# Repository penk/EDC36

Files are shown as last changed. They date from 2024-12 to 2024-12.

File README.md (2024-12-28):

## EDC36 - Minimalist 36-Key Split Keyboard (Reversible PCB)

The EDC36 is a split keyboard designed with simplicity and portability in mind. 

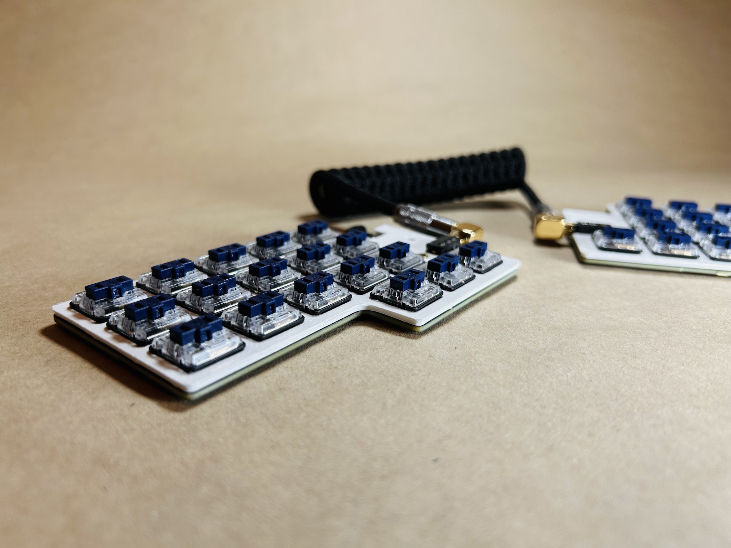
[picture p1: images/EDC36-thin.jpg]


## Bill of Materials (BOM)

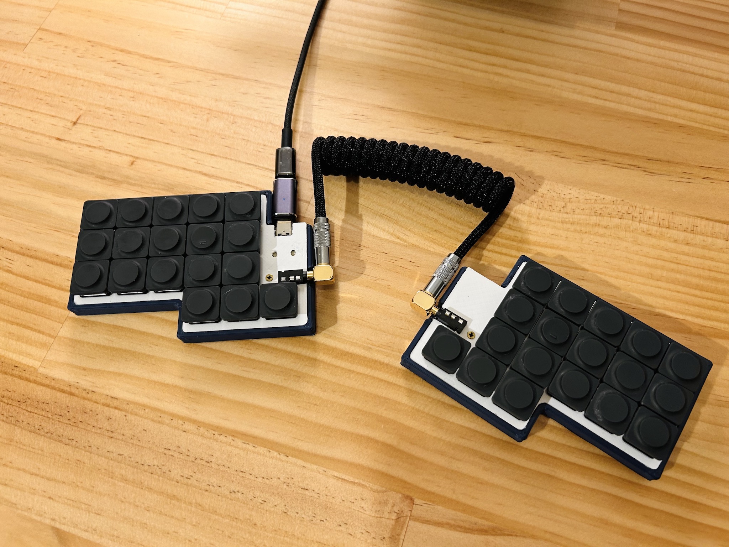
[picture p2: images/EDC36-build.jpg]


Quantity | Item
--- | ---
1 | RP2040-Zero (left half)
1 | RP2040-Tiny (right half)
2 | EDC36 PCB
36 | Choc v1 (PG1350) switches and keycaps 
36 | 1N4148SOD-123 diodes
2 | Audio jack 4-poles (TRRS)
2 | EDC36 case & plate
10 | M2×3 heat-set threaded inserts
10 | M2×5 countersunk screws

## Production Files

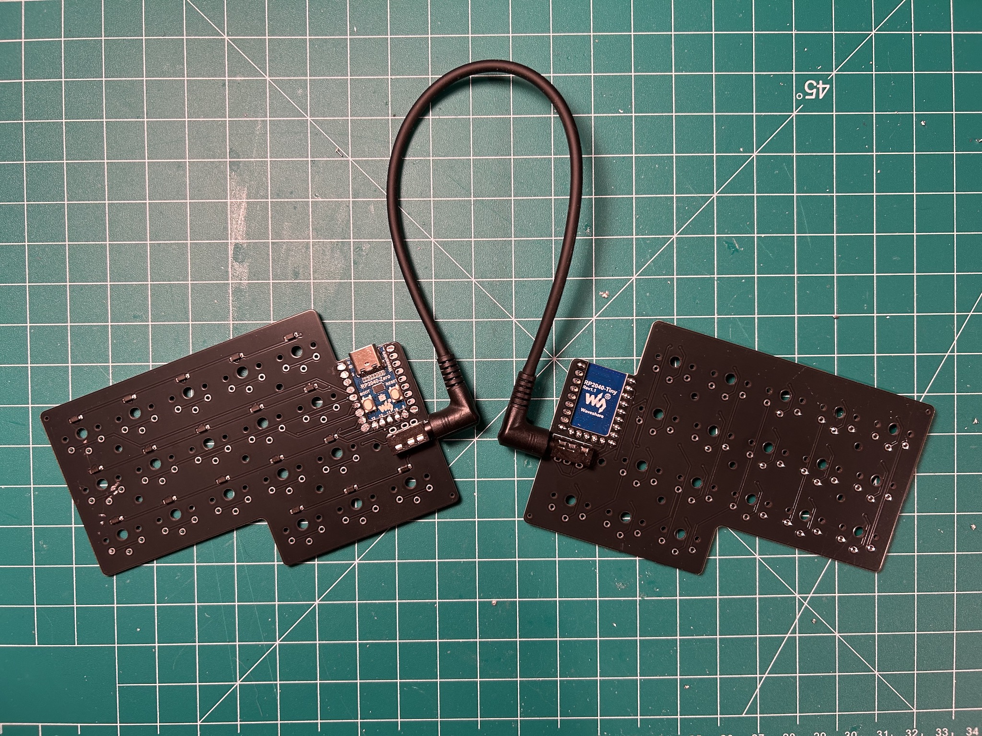
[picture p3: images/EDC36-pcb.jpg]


To place an order for the EDC36 PCB:

- Use the Gerber files available in the [production/](production/) folder.
- Optionally, the [BOM](production/BOM.csv) and [CPL](production/CPL.csv) files can be utilized with a PCBA service. All diodes are soldered to the front (top) side of the board.

The complete PCB design project is available in the [kicad/](kicad/) folder.

## 3D Printable Files

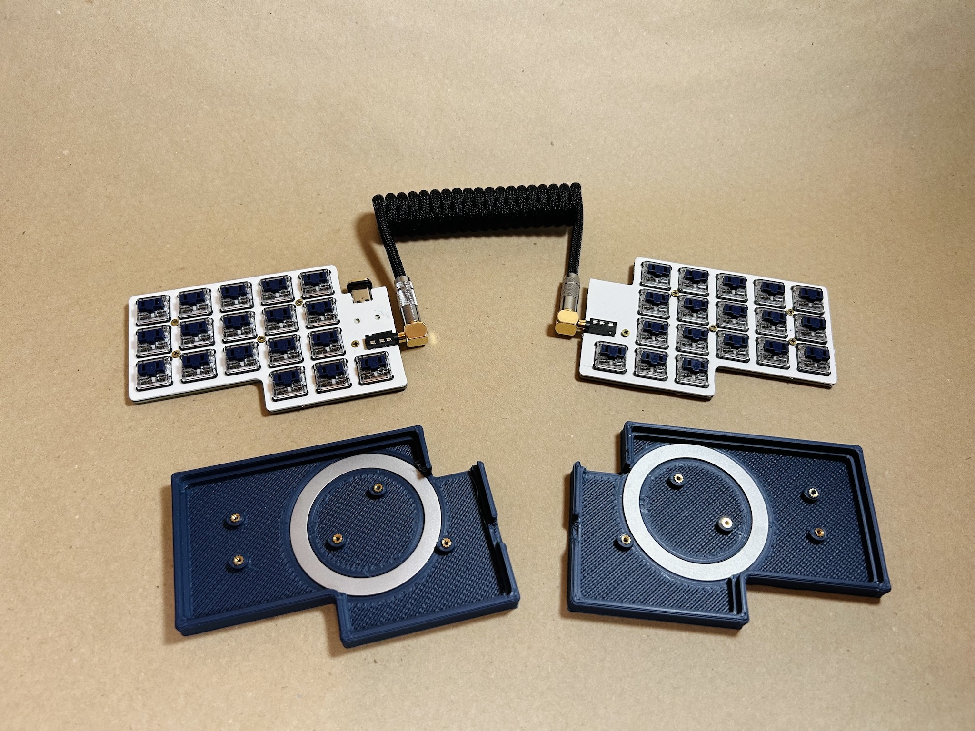
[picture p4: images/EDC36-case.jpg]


Print the case and plate using the provided [STL files](case/).

## Firmware

Precompiled VIA-enabled firmware:

- Flash `penk_edc36_default.uf2` under [firmware/](firmware/) to the RP2040 MCUs.
- Load the [via.json](firmware/QMK/keyboards/edc36/via.json) file in `Design` tab for [VIA](https://usevia.app) configuration.

QMK source is available under [firmware/QMK/keyboards/edc36](firmware/QMK/keyboards/edc36).

## Copyright and License
Copyright (c) 2024 Penk Chen. All rights reserved.

All files are licensed under the MIT license. For more information, see the [LICENSE](LICENSE).

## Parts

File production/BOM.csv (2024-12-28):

Designator | Footprint | Quantity | Value | LCSC Part #
D1, D10, D11, D12, D13, D14, D15, D16, D17, D18, D2, D3, D4, D5, D6, D7, D8, D9 | Diode_SOD-123 | 18 | Diode | C2972760

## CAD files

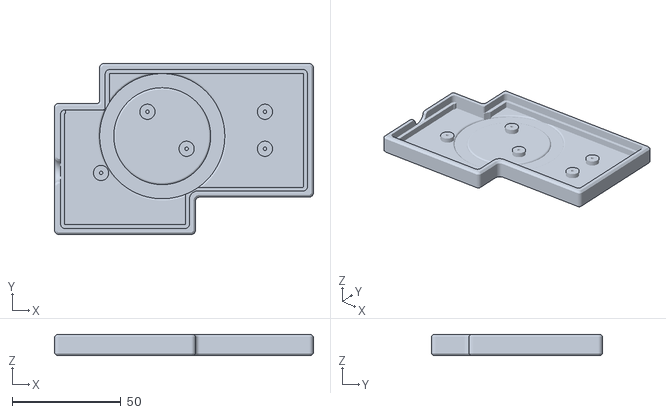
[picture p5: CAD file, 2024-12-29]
case/EDC36-case-right.stl
119.0 x 78.6 x 9.80

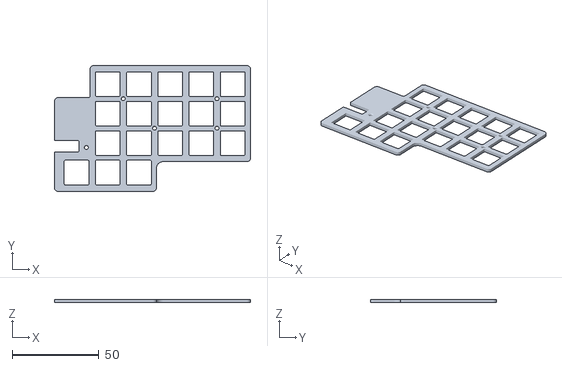
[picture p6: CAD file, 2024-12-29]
case/EDC36-plate-right.stl
113.0 x 72.6 x 2.00

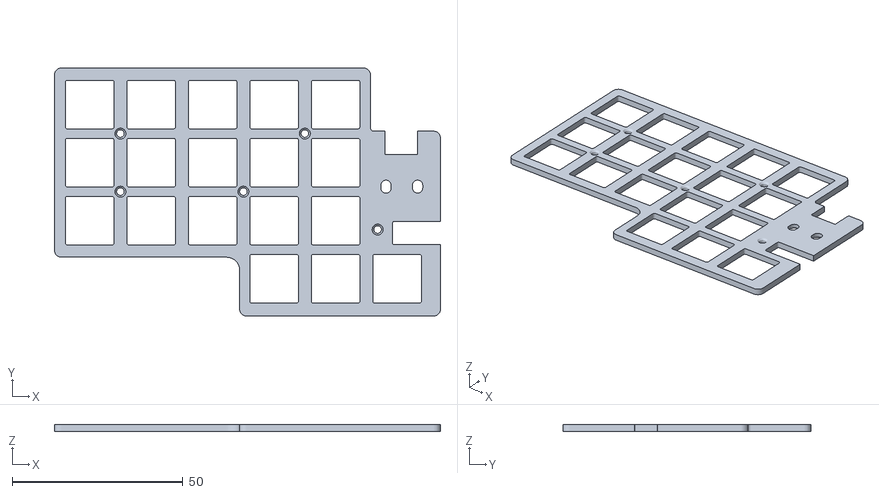
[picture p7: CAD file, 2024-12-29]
case/EDC36-plate-left.stl
113.0 x 72.6 x 2.00

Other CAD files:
case/EDC36-case-left.stl

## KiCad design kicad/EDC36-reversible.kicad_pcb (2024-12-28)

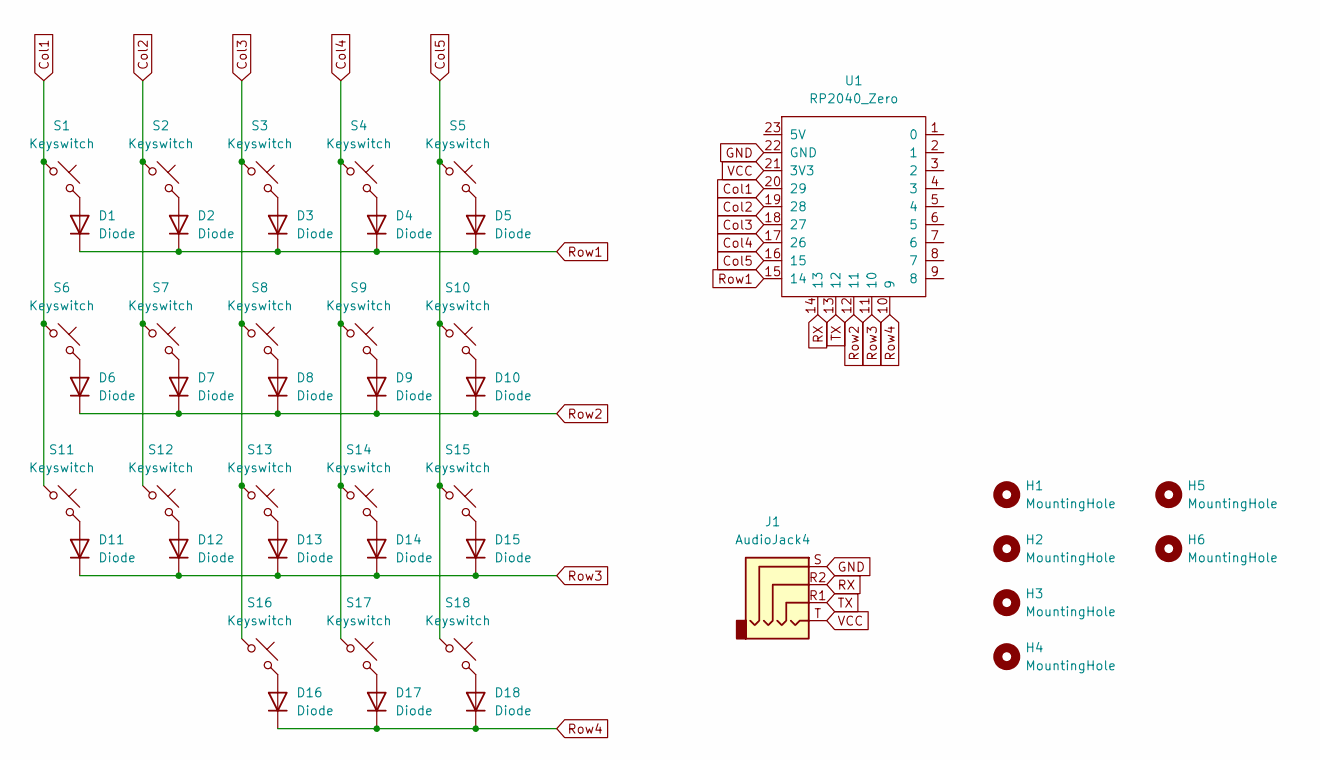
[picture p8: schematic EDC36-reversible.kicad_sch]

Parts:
D1, D2, D3, D4, D5, D6, D7, D8, D9, D10, D11, D12, D13, D14, D15, D16, D17, D18: Diode; Diode_SOD-123
H1, H2, H3, H4, H5, H6: MountingHole; MountingHole_2.2mm_M2
J1: AudioJack4; CON_MJ-4PP-9_Reversible
S1, S2, S3, S4, S5, S6, S7, S8, S9, S10, S11, S12, S13, S14, S15, S16, S17, S18: Keyswitch; SW_choc_Reversible_1u
U1: RP2040_Zero

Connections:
Col1: S1.1, S6.1, S11.1, U1.20 (29)
Col2: S2.1, S7.1, S12.1, U1.19 (28)
Col3: S3.1, S8.1, S13.1, S16.1, U1.18 (27)
Col4: S4.1, S9.1, S14.1, S17.1, U1.17 (26)
Col5: S5.1, S10.1, S15.1, S18.1, U1.16 (15)
GND: J1.S, U1.22 (GND)
unnamed: D1.2 (A), S1.2
unnamed: D2.2 (A), S2.2
unnamed: D3.2 (A), S3.2
unnamed: D4.2 (A), S4.2
unnamed: D5.2 (A), S5.2
unnamed: D6.2 (A), S6.2
unnamed: D7.2 (A), S7.2
unnamed: D8.2 (A), S8.2
unnamed: D9.2 (A), S9.2
unnamed: D10.2 (A), S10.2
unnamed: D11.2 (A), S11.2
unnamed: D12.2 (A), S12.2
unnamed: D13.2 (A), S13.2
unnamed: D14.2 (A), S14.2
unnamed: D15.2 (A), S15.2
unnamed: D16.2 (A), S16.2
unnamed: D17.2 (A), S17.2
unnamed: D18.2 (A), S18.2
RX: J1.R2, U1.14 (13)
Row1: D1.1 (K), D2.1 (K), D3.1 (K), D4.1 (K), D5.1 (K), U1.15 (14)
Row2: D6.1 (K), D7.1 (K), D8.1 (K), D9.1 (K), D10.1 (K), U1.12 (11)
Row3: D11.1 (K), D12.1 (K), D13.1 (K), D14.1 (K), D15.1 (K), U1.11 (10)
Row4: D16.1 (K), D17.1 (K), D18.1 (K), U1.10 (9)
TX: J1.R1, U1.13 (12)
VCC: J1.T, U1.21 (3V3)

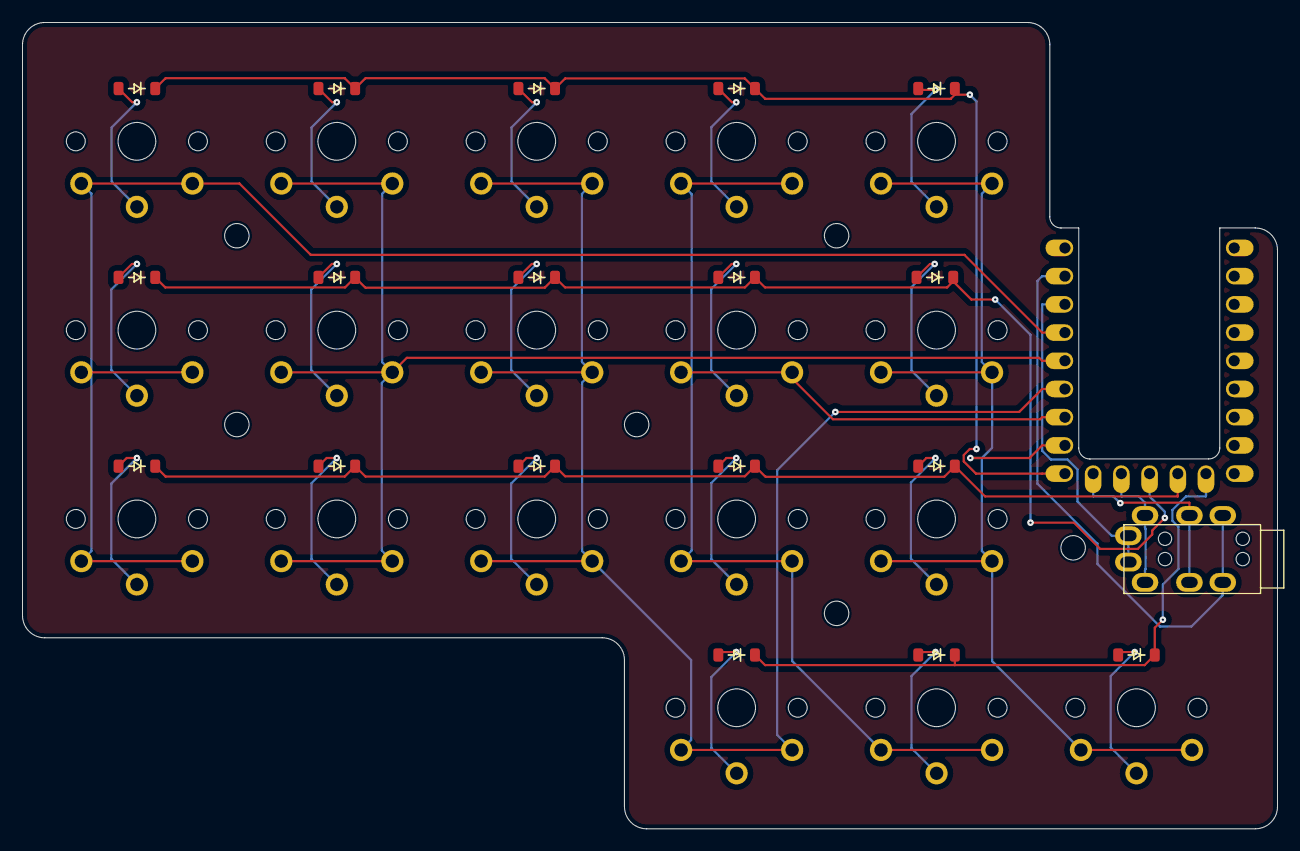
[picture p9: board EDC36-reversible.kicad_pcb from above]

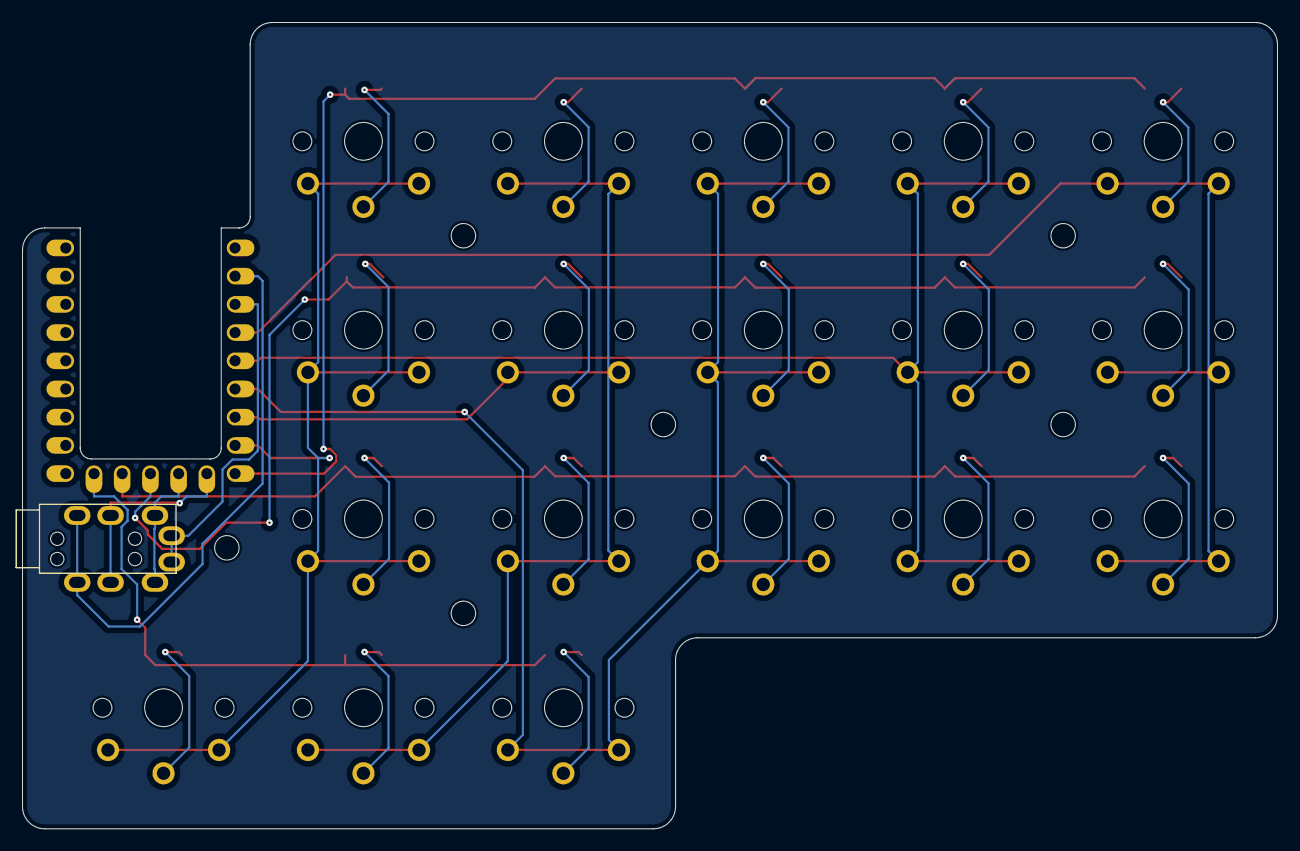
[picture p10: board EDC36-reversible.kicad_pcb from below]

Board: 2 copper layers, 113.0 x 72.6 mm, 44 parts (19 on the bottom side), 31 nets.
